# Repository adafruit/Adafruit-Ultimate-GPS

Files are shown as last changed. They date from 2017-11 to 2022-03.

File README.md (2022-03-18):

## Adafruit Ultimate GPS PCB

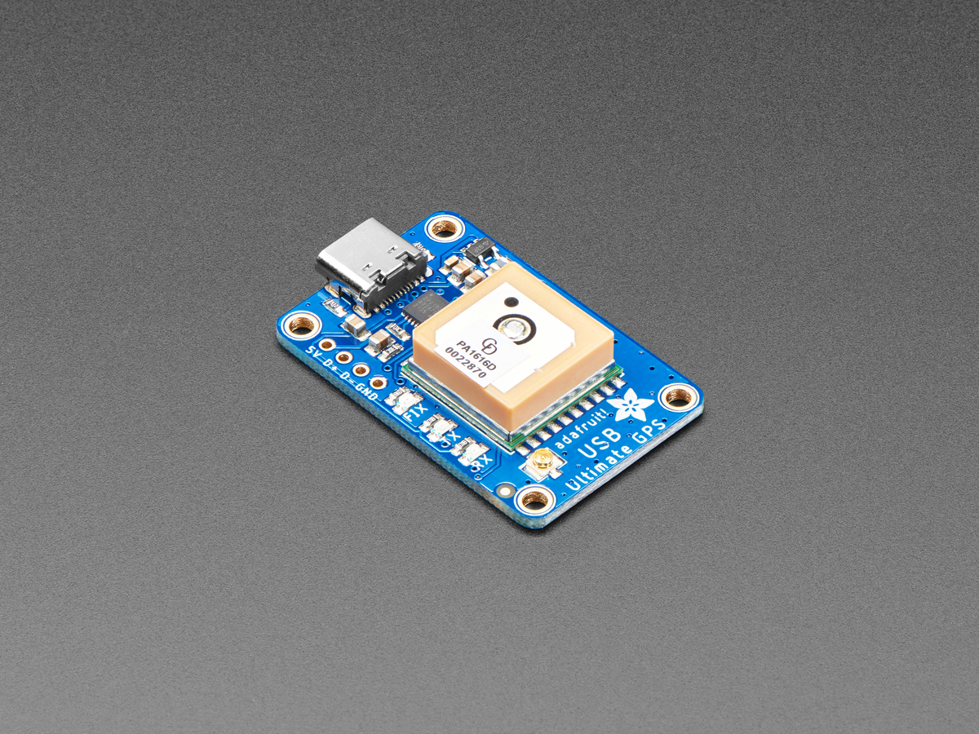
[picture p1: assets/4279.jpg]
<a href="http://www.adafruit.com/products/4279"><br/>
Click here to purchase one from the Adafruit shop</a>
Other versions:
* <a href="https://www.adafruit.com/product/746">Adafruit Ultimate GPS Breakout</a>
* <a href="https://www.adafruit.com/product/3133">Adafruit Ultimate GPS FeatherWing</a>
* <a href="https://www.adafruit.com/product/1272">Adafruit Ultimate GPS Logger Shield</a>
* <a href="https://www.adafruit.com/product/2324">Adafruit Ultimate GPS HAT for Raspberry Pi</a>
* <a href="https://www.adafruit.com/product/1059">Flora Wearable Ultimate GPS Module</a>

PCB files for the Adafruit Ultimate GPS. 

Format is EagleCAD schematic and board layout
* https://www.adafruit.com/product/4279
* https://www.adafruit.com/product/746
* https://www.adafruit.com/product/3133
* https://www.adafruit.com/product/1272
* https://www.adafruit.com/product/2324
* https://www.adafruit.com/product/1059

### Description

These boards are built around the MTK3339 chipset, a no-nonsense, high-quality GPS module that can track up to 22 satellites on 66 channels, has an excellent high-sensitivity receiver (-165 dBm tracking!), and a built-in antenna. It can do up to 10 location updates a second for high speed, high sensitivity logging, or tracking. Power usage is incredibly low, only 20 mA during navigation.

We believe this is the Ultimate GPS module, so we named it that. It's got everything you want and more:

* -165 dBm sensitivity, 10 Hz updates, 66 channels
* 5V friendly design and only 20mA current draw
* RTC battery-compatible
* Built-in datalogging
* PPS output on fix
* Internal patch antenna + u.FL connector for external active antenna
* Fix status LED
* Pulse-Per-Second output

### License

Adafruit invests time and resources providing this open source design, please support Adafruit and open-source hardware by purchasing products from [Adafruit](https://www.adafruit.com)!

Designed by Limor Fried/Ladyada for Adafruit Industries.

Creative Commons Attribution/Share-Alike, all text above must be included in any redistribution. 
See license.txt for additional details.

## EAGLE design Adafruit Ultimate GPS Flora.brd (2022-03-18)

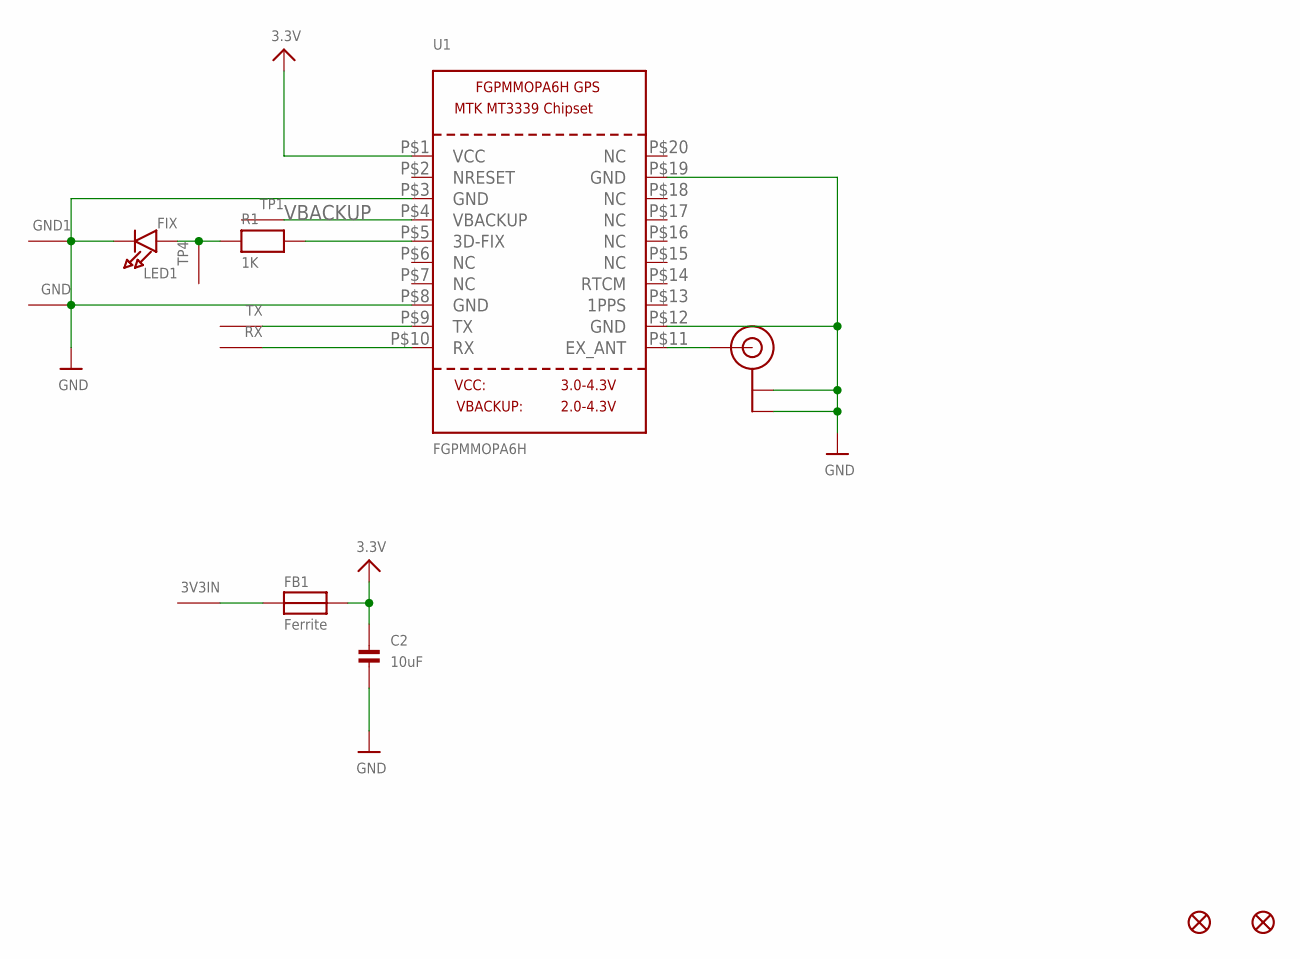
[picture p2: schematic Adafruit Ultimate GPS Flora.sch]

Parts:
3V3IN: SEWTAP-2.0IN; SEWINGTAP_2.0
C2: 10uF; 0805
FB1: Ferrite; 0805
FID1, FID2: FIDUCIAL""; FIDUCIAL_1MM
GND, GND1: SEWTAP-2.0IN; SEWINGTAP_2.0
LED1: FIX; CHIPLED_0805
R1: 1K; 0805
RX: SEWTAP-2.0IN; SEWINGTAP_2.0
TP1, TP4: SEWTAP-2.0IN; SEWINGTAP_2.0
TX: SEWTAP-2.0IN; SEWINGTAP_2.0
U1: FGPMMOPA6H
U$20: U.FL

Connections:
3.3V: C2.1, FB1.2, U1.P$1 (VCC)
GND: C2.2, GND.P$1, GND1.P$1, LED1.C, U1.P$3 (GND), U1.P$8 (GND), U1.P$12 (GND), U1.P$19 (GND), U$20.P$1 (GND), U$20.P$2 (GND)
unnamed: LED1.A, R1.1, TP4.P$1
unnamed: R1.2, U1.P$5 (3D-FIX)
unnamed: 3V3IN.P$1, FB1.1
unnamed: U1.P$11 (EX_ANT), U$20.P$3 (SIGNAL)
RX: RX.P$1, U1.P$10 (RX)
TX: TX.P$1, U1.P$9 (TX)
VBACKUP: TP1.P$1, U1.P$4 (VBACKUP)

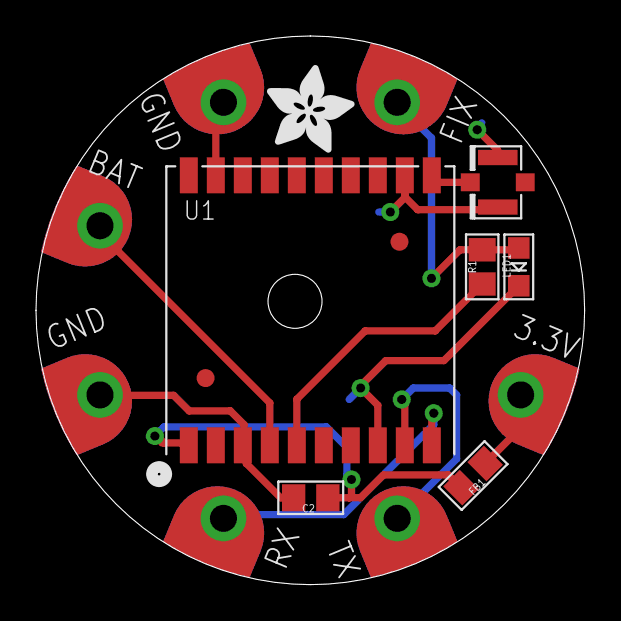
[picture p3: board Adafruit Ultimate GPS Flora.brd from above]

Board: 2 copper layers, 30.5 x 30.5 mm, 17 parts (1 on the bottom side), 9 nets.

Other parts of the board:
U$6: ADAFRUIT_5MM
U$7: FLORASMALL

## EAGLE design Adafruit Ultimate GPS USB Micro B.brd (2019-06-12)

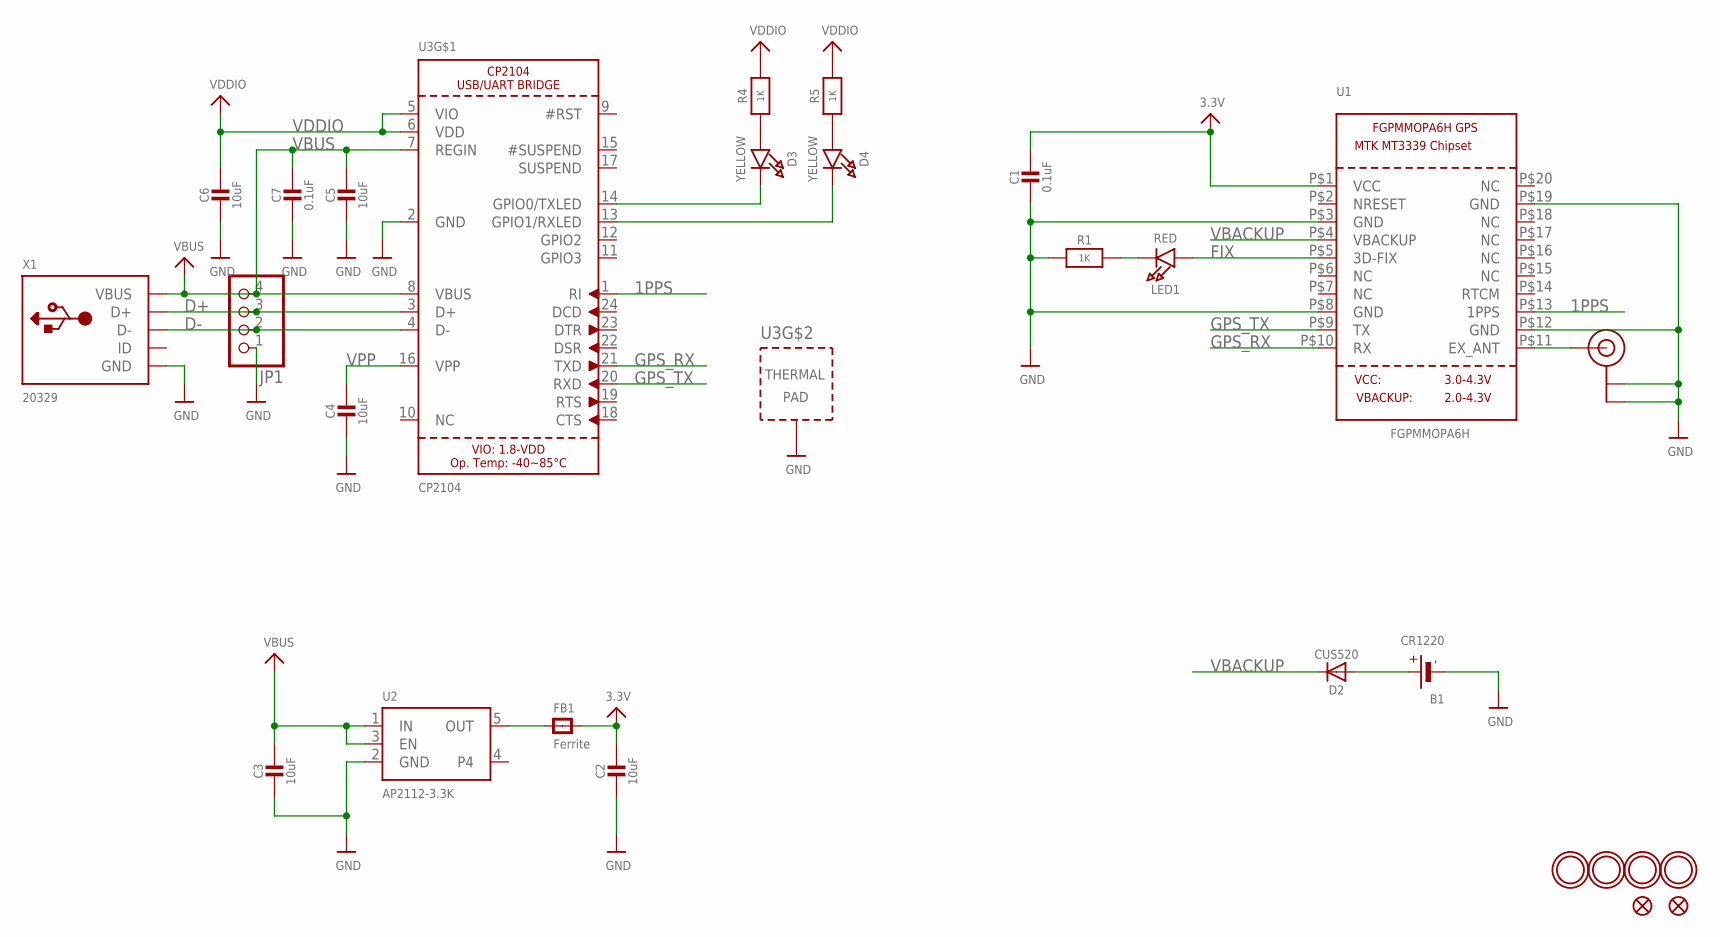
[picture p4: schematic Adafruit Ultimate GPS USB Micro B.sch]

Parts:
B1: CR1220
C1, C7: 0.1uF; 0603-NO
C2, C3, C4, C5, C6: 10uF; 0805-NO
D2: CUS520; SOD-323
D3, D4: YELLOW; CHIPLED_0805_NOOUTLINE
FB1: Ferrite; 0805-NO
FID1, FID2: FIDUCIAL_1MM
JP1: HEADER-1X4ROUND; 1X04_ROUND
LED1: RED; CHIPLED_0805_NOOUTLINE
R1, R4, R5: 1K; 0603-NO
U1: FGPMMOPA6H
U2: AP2112-3.3K; SOT23-5
U3: CP2104; QFN24_4MM_SMSC
U$8, U$9, U$35, U$36: MOUNTINGHOLE2.5; MOUNTINGHOLE_2.5_PLATED
U$20: U.FL
X1: 20329; 4UCONN_20329_V2

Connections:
1PPS: U1.P$13 (1PPS), U3.1 (RI)
3.3V: C1.1, C2.1, FB1.2, U1.P$1 (VCC)
D+: JP1.3, U3.3 (D+), X1.D+
D-: JP1.2, U3.4 (D-), X1.D-
FIX: LED1.A, U1.P$5 (3D-FIX)
GND: B1.-, C1.2, C2.2, C3.2, C4.2, C5.2, C6.2, C7.2, JP1.1, R1.1, U1.P$3 (GND), U1.P$8 (GND), U1.P$12 (GND), U1.P$19 (GND), U2.2 (GND), U3.2 (GND), U3.THERM (TP), U$20.P$1 (GND), U$20.P$2 (GND), X1.BASE@1 (GND), X1.BASE@2 (GND), X1.GND, X1.SPRT@1 (GND), X1.SPRT@2 (GND), X1.SPRT@3 (GND), X1.SPRT@4 (GND)
GPS_RX: U1.P$10 (RX), U3.21 (TXD)
GPS_TX: U1.P$9 (TX), U3.20 (RXD)
unnamed: B1.+$1 (+), B1.+$2 (+), D2.A
unnamed: LED1.C, R1.2
unnamed: FB1.1, U2.5 (OUT)
unnamed: U1.P$11 (EX_ANT), U$20.P$3 (SIGNAL)
unnamed: D3.A, R4.1
unnamed: D4.A, R5.1
unnamed: D3.C, U3.14 (GPIO0/TXLED)
unnamed: D4.C, U3.13 (GPIO1/RXLED)
VBACKUP: D2.C, U1.P$4 (VBACKUP)
VBUS: C3.1, C5.1, C7.1, JP1.4, U2.1 (IN), U2.3 (EN), U3.7 (REGIN), U3.8 (VBUS), X1.VBUS
VDDIO: C6.1, R4.2, R5.2, U3.5 (VIO), U3.6 (VDD)
VPP: C4.1, U3.16 (VPP)

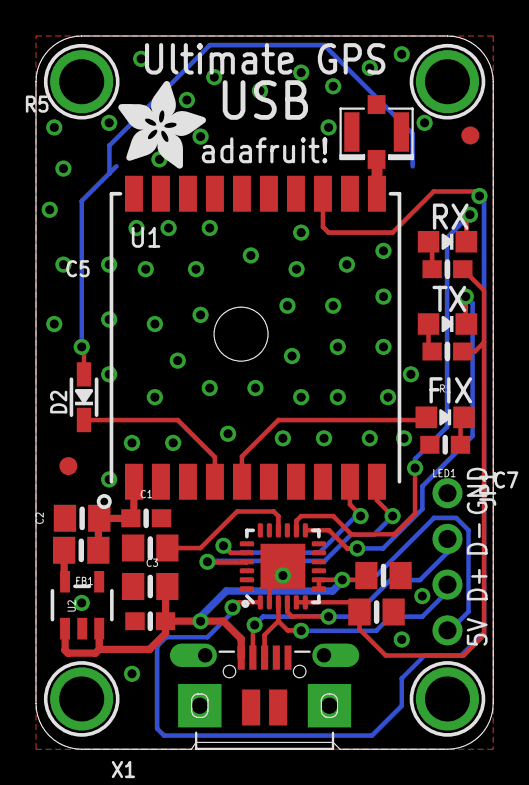
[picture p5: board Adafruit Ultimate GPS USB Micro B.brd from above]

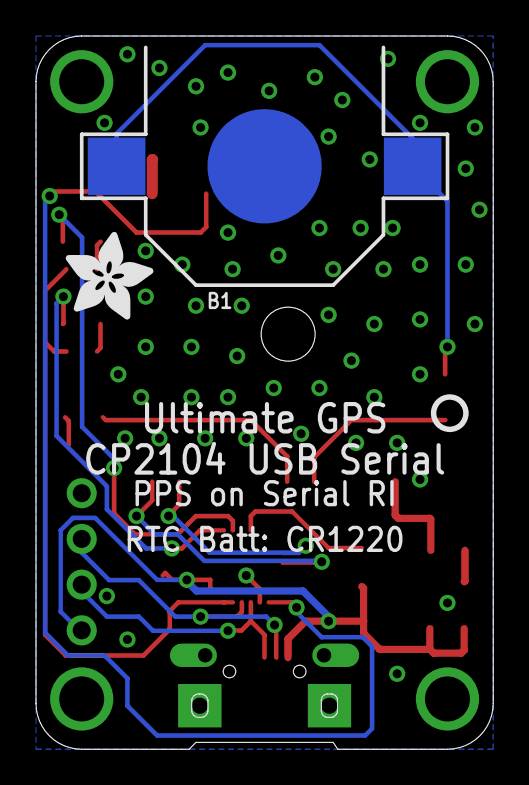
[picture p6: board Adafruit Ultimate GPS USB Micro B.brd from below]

Board: 2 copper layers, 25.4 x 39.6 mm, 31 parts (3 on the bottom side), 20 nets.

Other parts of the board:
U$13, U$18: ADAFRUIT_5MM
U$16: PCBFEAT-REV-040

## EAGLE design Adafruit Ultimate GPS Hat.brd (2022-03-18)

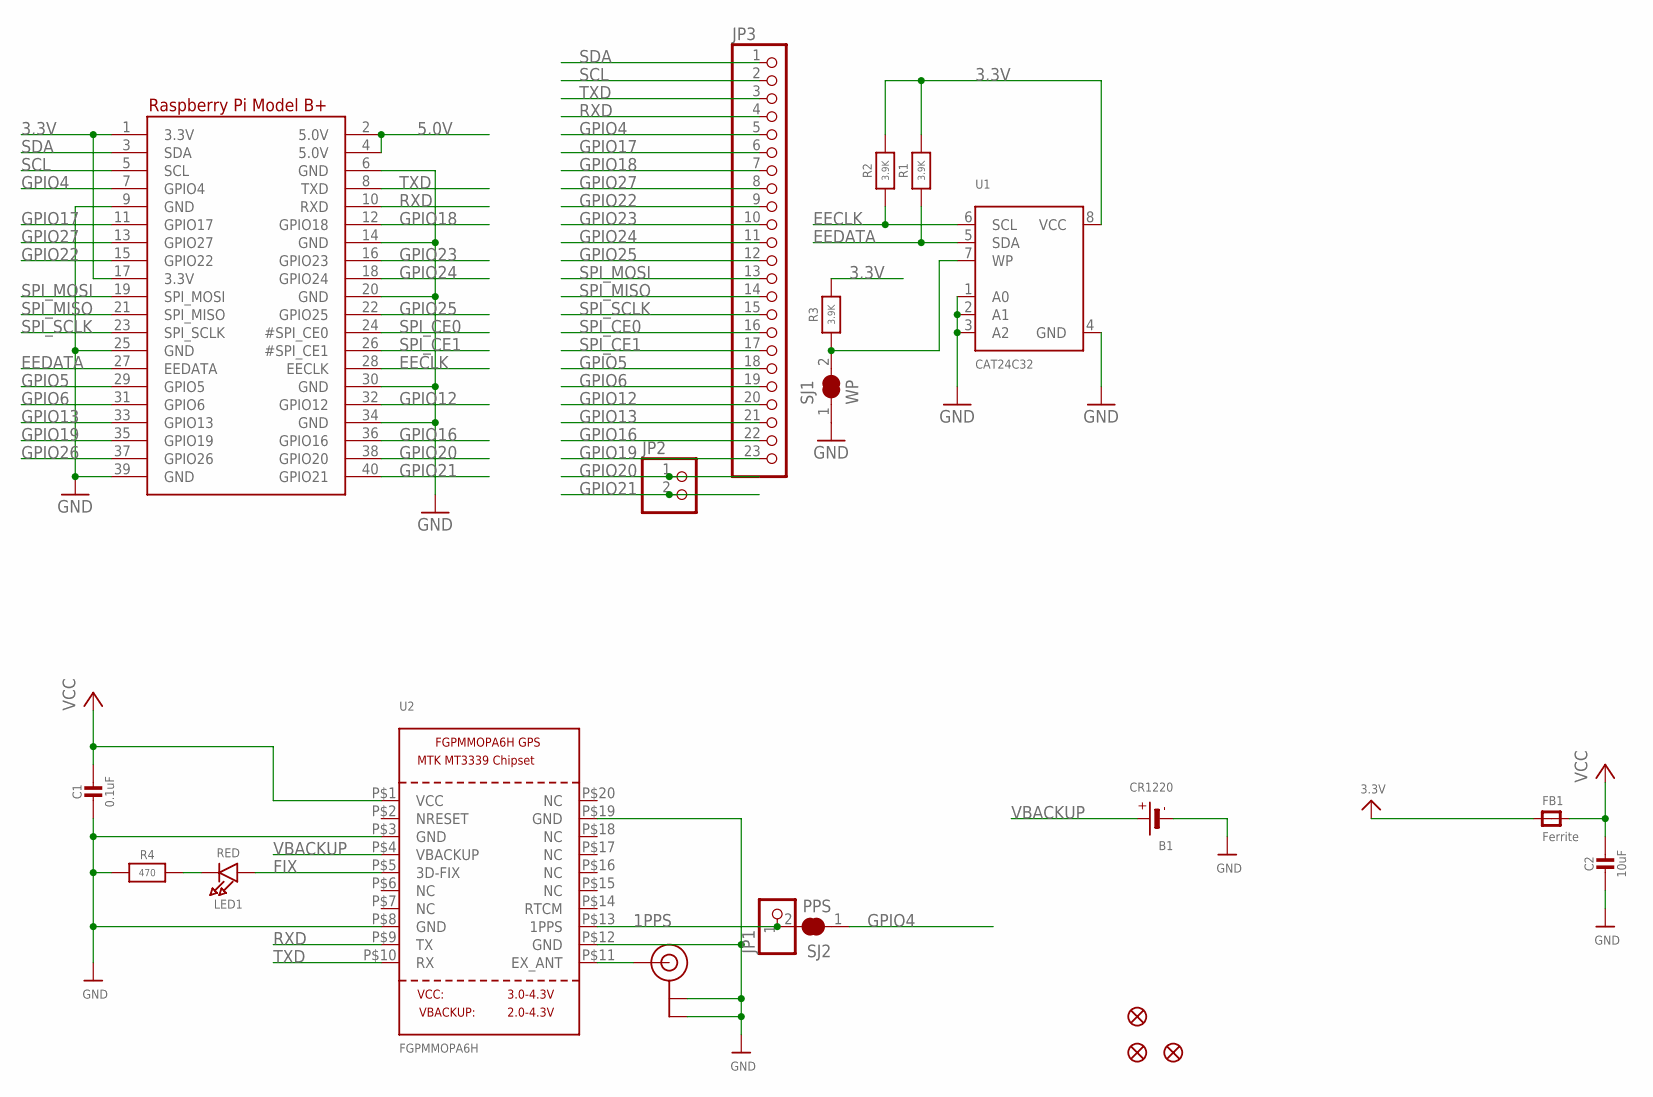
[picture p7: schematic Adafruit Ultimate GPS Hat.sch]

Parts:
B1: CR1220
C1: 0.1uF; 0805-NO
C2: 10uF; 0805-NO
FB1: Ferrite; 0805
FID1, FID2, FID3: FIDUCIAL_1MM
JP1: PINHD-1X1CB; 1X01-CLEANBIG
JP2: HEADER-1X2ROUND; 1X02_ROUND
JP3: HEADER-1X23; 1X23_ROUND_70MIL
LED1: RED; CHIPLED_0805
R1, R2, R3: 3.9K; 0805-NO
R4: 470; 0805-NO
RPI1: RASPBERRYPI_BPLUS_HATSLOTS; PI_HAT_SLOTS
SJ1: WP; SOLDERJUMPER_CLOSEDWIRE
SJ2: PPS; SOLDERJUMPER_CLOSEDWIRE
U1: CAT24C32; SOIC8_150MIL
U2: FGPMMOPA6H
U$20: U.FL

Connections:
1PPS: JP1.1, SJ2.2, U2.P$13 (1PPS)
3.3V: FB1.1, R1.2, R2.2, R3.2, RPI1.1 (3.3V), RPI1.17 (3.3V), U1.8 (VCC)
5.0V: RPI1.2 (5.0V), RPI1.4 (5.0V)
EECLK: R2.1, RPI1.28 (EECLK), U1.6 (SCL)
EEDATA: R1.1, RPI1.27 (EEDATA), U1.5 (SDA)
FIX: LED1.A, U2.P$5 (3D-FIX)
GND: B1.-, C1.2, C2.2, R4.1, RPI1.6 (GND), RPI1.9 (GND), RPI1.14 (GND), RPI1.20 (GND), RPI1.25 (GND), RPI1.30 (GND), RPI1.34 (GND), RPI1.39 (GND), SJ1.1, U1.1 (A0), U1.2 (A1), U1.3 (A2), U1.4 (GND), U2.P$3 (GND), U2.P$8 (GND), U2.P$12 (GND), U2.P$19 (GND), U$20.P$1 (GND), U$20.P$2 (GND)
GPIO4: JP3.5, RPI1.7 (GPIO4), SJ2.1
GPIO5: JP3.18, RPI1.29 (GPIO5)
GPIO6: JP3.19, RPI1.31 (GPIO6)
GPIO12: JP3.20, RPI1.32 (GPIO12)
GPIO13: JP3.21, RPI1.33 (GPIO13)
GPIO16: JP3.22, RPI1.36 (GPIO16)
GPIO17: JP3.6, RPI1.11 (GPIO17)
GPIO18: JP3.7, RPI1.12 (GPIO18)
GPIO19: JP3.23, RPI1.35 (GPIO19)
GPIO20: JP2.1, RPI1.38 (GPIO20)
GPIO21: JP2.2, RPI1.40 (GPIO21)
GPIO22: JP3.9, RPI1.15 (GPIO22)
GPIO23: JP3.10, RPI1.16 (GPIO23)
GPIO24: JP3.11, RPI1.18 (GPIO24)
GPIO25: JP3.12, RPI1.22 (GPIO25)
GPIO26: RPI1.37 (GPIO26)
GPIO27: JP3.8, RPI1.13 (GPIO27)
unnamed: R3.1, SJ1.2, U1.7 (WP)
unnamed: LED1.C, R4.2
unnamed: U2.P$11 (EX_ANT), U$20.P$3 (SIGNAL)
RXD: JP3.4, RPI1.10 (RXD), U2.P$9 (TX)
SCL: JP3.2, RPI1.5 (SCL)
SDA: JP3.1, RPI1.3 (SDA)
SPI_CE0: JP3.16, RPI1.24 (#SPI_CE0)
SPI_CE1: JP3.17, RPI1.26 (#SPI_CE1)
SPI_MISO: JP3.14, RPI1.21 (SPI_MISO)
SPI_MOSI: JP3.13, RPI1.19 (SPI_MOSI)
SPI_SCLK: JP3.15, RPI1.23 (SPI_SCLK)
TXD: JP3.3, RPI1.8 (TXD), U2.P$10 (RX)
VBACKUP: B1.+$1 (+), B1.+$2 (+), U2.P$4 (VBACKUP)
VCC: C1.1, C2.1, FB1.2, U2.P$1 (VCC)

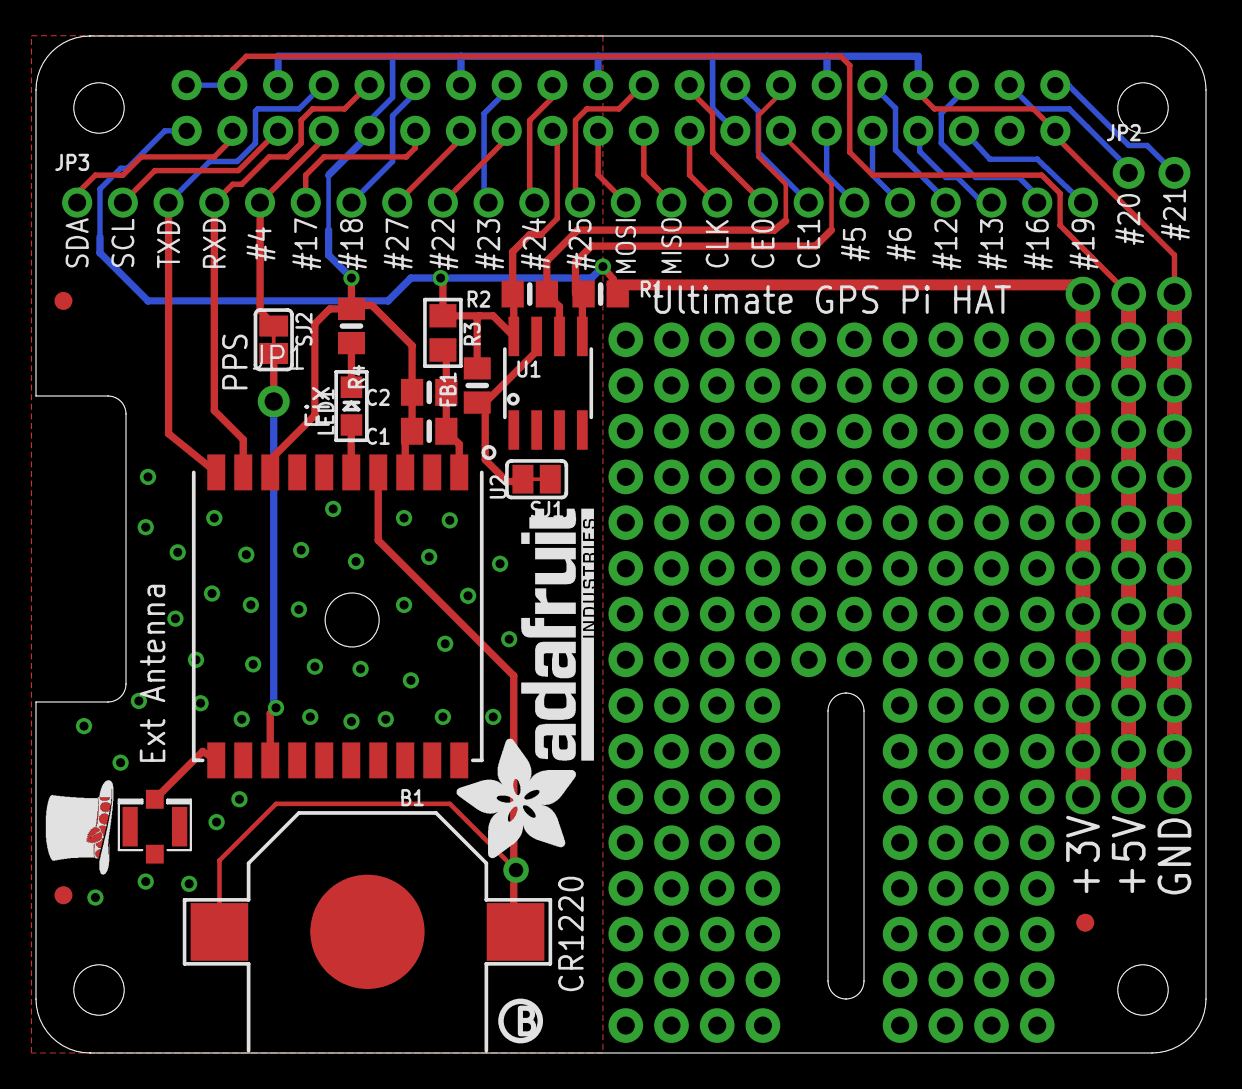
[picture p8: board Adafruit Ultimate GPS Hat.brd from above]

Board: 2 copper layers, 65.0 x 56.5 mm, 24 parts (0 on the bottom side), 37 nets.

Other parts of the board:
U$3: ADAFRUIT_TEXT_20MM
U$4: PIHATLOGO
U$6: PCBFEAT-REV-056

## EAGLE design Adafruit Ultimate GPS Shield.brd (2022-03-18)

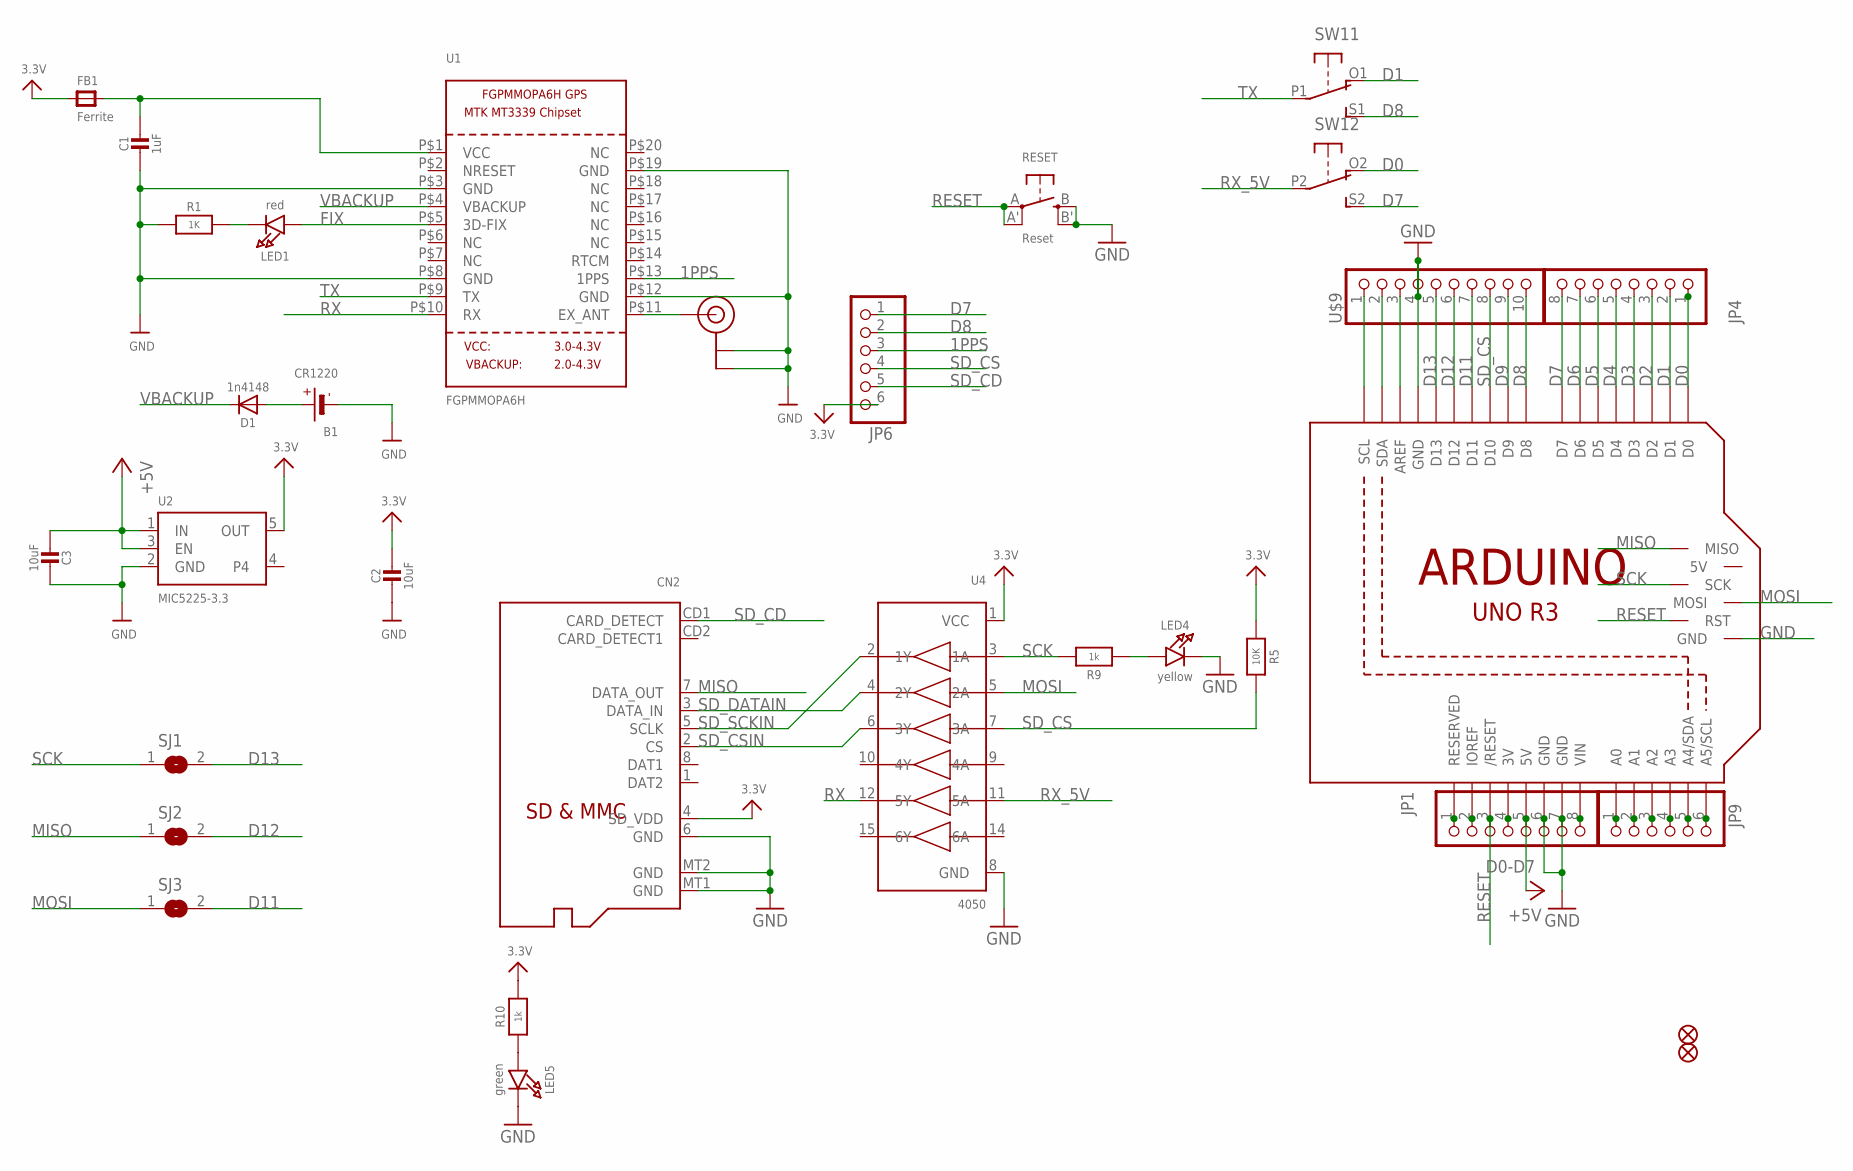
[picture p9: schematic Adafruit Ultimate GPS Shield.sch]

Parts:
B1: CR1220
C1: 1uF; 0805-NO
C2, C3: 10uF; 0805-NO
CN2: MICROSD
D1: 1n4148; SOD-323
FB1: Ferrite; 0805
FID1, FID2: FIDUCIAL""; FIDUCIAL_1MM
JP1: D0-D7; 1X08-BIG
JP4: PINHD-1X8BIG; 1X08-BIG
JP6, JP9: PINHD-1X6B; 1X06-BIG
LED1: red; CHIPLED_0805_NOOUTLINE
LED4: yellow; CHIPLED_0805_NOOUTLINE
LED5: green; CHIPLED_0805_NOOUTLINE
M1: ARDUINO_R3_ICSP_NODIM; ARDUINOR3_ICSP_NODIM
R1: 1K; 0805-NO
R5: 10K; 0805-NO
R9, R10: 1k; 0805-NO
RESET: Reset; EVQ-Q2
SJ1, SJ2, SJ3: SOLDERJUMPER; SOLDERJUMPER_ARROW_NOPASTE
SW1: DPDT-EG1390; EG1390
U1: FGPMMOPA6H
U2: MIC5225-3.3; SOT23-5
U4: 4050; SOIC16
U$9: PINHD-1X10; 1X10-BIG
U$20: U.FL

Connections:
1PPS: JP6.3, U1.P$13 (1PPS)
3.3V: C2.1, CN2.4 (SD_VDD), FB1.1, JP6.6, R5.1, R10.2, U2.5 (OUT), U4.1 (VCC)
3V: JP1.4, M1.3V
+5V: C3.1, JP1.5, M1.5V, U2.1 (IN), U2.3 (EN)
A0: JP9.1, M1.A0
A1: JP9.2, M1.A1
A2: JP9.3, M1.A2
A3: JP9.4, M1.A3
A4: JP9.5, M1.A4 (A4/SDA)
A5: JP9.6, M1.A5 (A5/SCL)
AREF: M1.AREF, U$9.3
D0: JP4.1, M1.D0, SW1.O2 (O)
D1: JP4.2, M1.D1, SW1.O1 (O)
D2: JP4.3, M1.D2
D3: JP4.4, M1.D3
D4: JP4.5, M1.D4
D5: JP4.6, M1.D5
D6: JP4.7, M1.D6
D7: JP4.8, JP6.1, M1.D7, SW1.S2 (S)
D8: JP6.2, M1.D8, SW1.S1 (S), U$9.10
D9: M1.D9, U$9.9
D11: M1.D11, SJ3.2, U$9.7
D12: M1.D12, SJ2.2, U$9.6
D13: M1.D13, SJ1.2, U$9.5
FIX: LED1.A, U1.P$5 (3D-FIX)
GND: B1.-, C1.2, C2.2, C3.2, CN2.6 (GND), CN2.MT1 (GND), CN2.MT2 (GND), JP1.6, JP1.7, LED4.C, LED5.C, M1.GND, M1.GND@1 (GND), M1.GND@2 (GND), M1.GND@3 (GND), R1.1, RESET.B (S), RESET.B' (S1), U1.P$3 (GND), U1.P$8 (GND), U1.P$12 (GND), U1.P$19 (GND), U2.2 (GND), U4.8 (GND), U$9.4, U$20.P$1 (GND), U$20.P$2 (GND)
IOREF: JP1.2, M1.IOREF
MISO: CN2.7 (DATA_OUT), M1.MISO, SJ2.1
MOSI: M1.MOSI, SJ3.1, U4.5 (2A)
unnamed: C1.1, FB1.2, U1.P$1 (VCC)
unnamed: LED1.C, R1.2
unnamed: B1.+$1 (+), B1.+$2 (+), D1.A
unnamed: U1.P$11 (EX_ANT), U$20.P$3 (SIGNAL)
unnamed: LED4.A, R9.1
unnamed: LED5.A, R10.1
NC: JP1.1, M1.RESERVED
RESET: JP1.3, M1.RESET (/RESET), M1.RESET_ICSP (RST), RESET.A, RESET.A' (P1)
RX: U1.P$10 (RX), U4.12 (5Y)
RX_5V: SW1.P2, U4.11 (5A)
SCK: M1.SCK, R9.2, SJ1.1, U4.3 (1A)
SCL: M1.SCL, U$9.1
SDA: M1.SDA, U$9.2
SD_CD: CN2.CD1 (CARD_DETECT), JP6.5
SD_CS: JP6.4, M1.D10, R5.2, U4.7 (3A), U$9.8
SD_CSIN: CN2.2 (CS), U4.6 (3Y)
SD_DATAIN: CN2.3 (DATA_IN), U4.4 (2Y)
SD_SCKIN: CN2.5 (SCLK), U4.2 (1Y)
TX: SW1.P1, U1.P$9 (TX)
VBACKUP: D1.C, U1.P$4 (VBACKUP)
VIN: JP1.8, M1.VIN

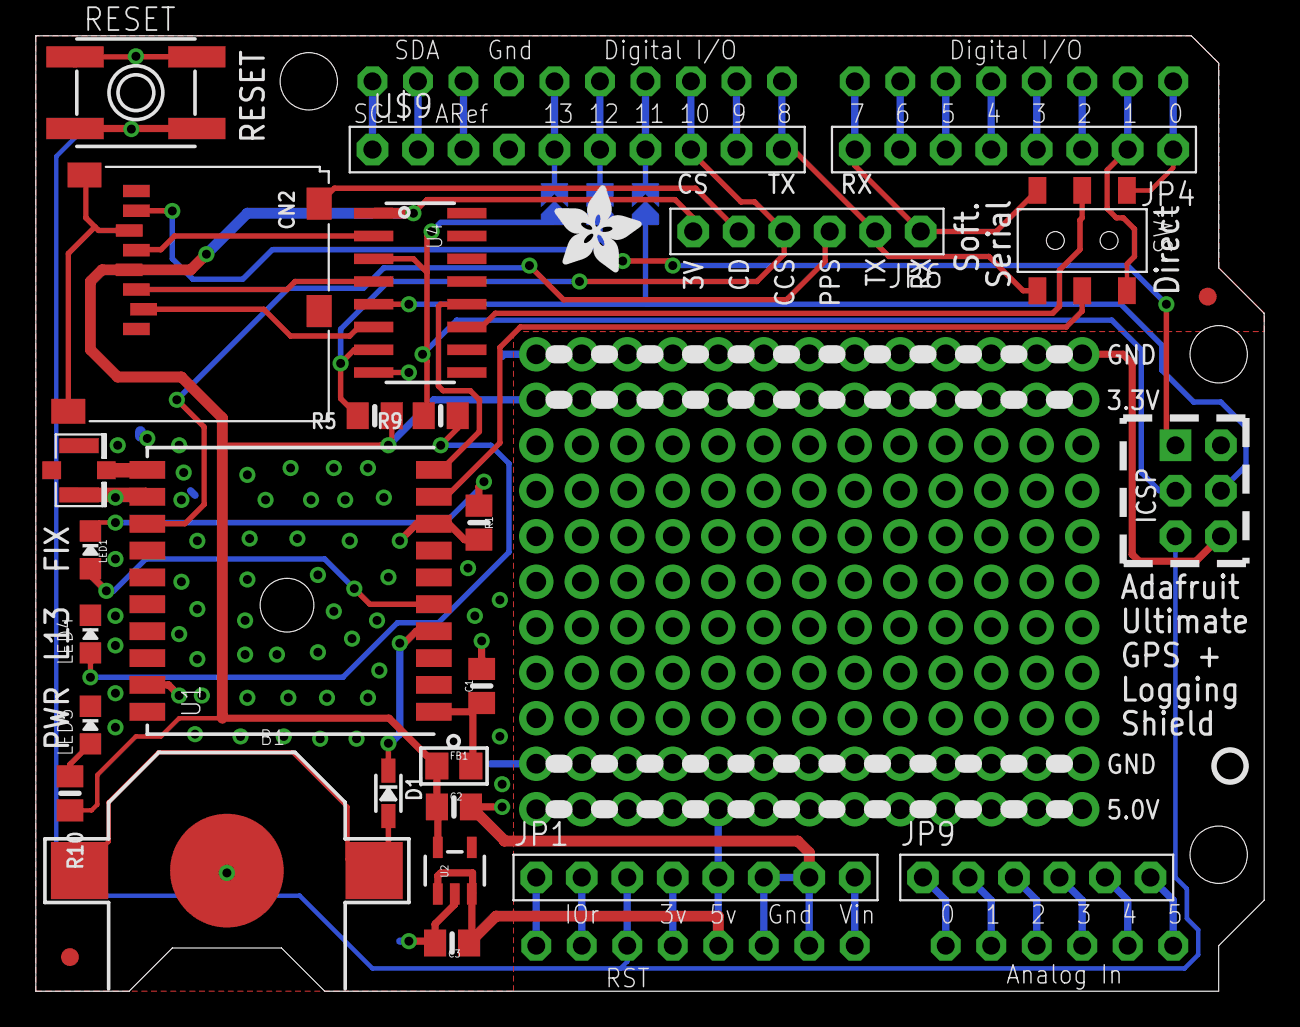
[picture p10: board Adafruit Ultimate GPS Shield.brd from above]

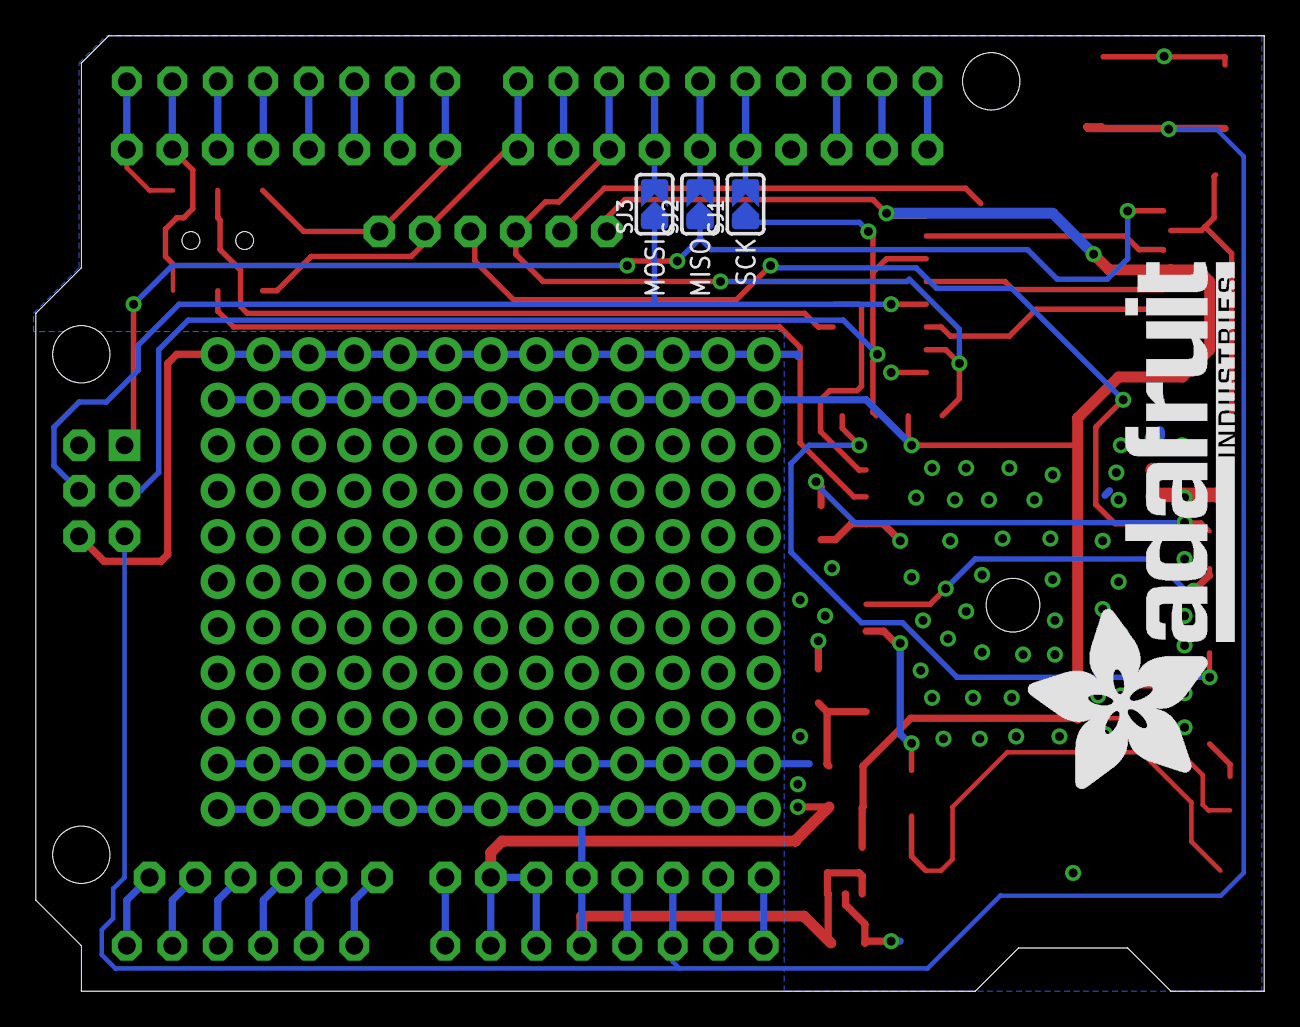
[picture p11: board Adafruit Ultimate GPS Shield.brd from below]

Board: 2 copper layers, 68.6 x 53.3 mm, 34 parts (4 on the bottom side), 50 nets.

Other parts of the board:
U$13: ADAFRUIT_5MM
U$15: ADAFRUIT_TEXT_30MM
U$16: PCBFEAT-REV-040

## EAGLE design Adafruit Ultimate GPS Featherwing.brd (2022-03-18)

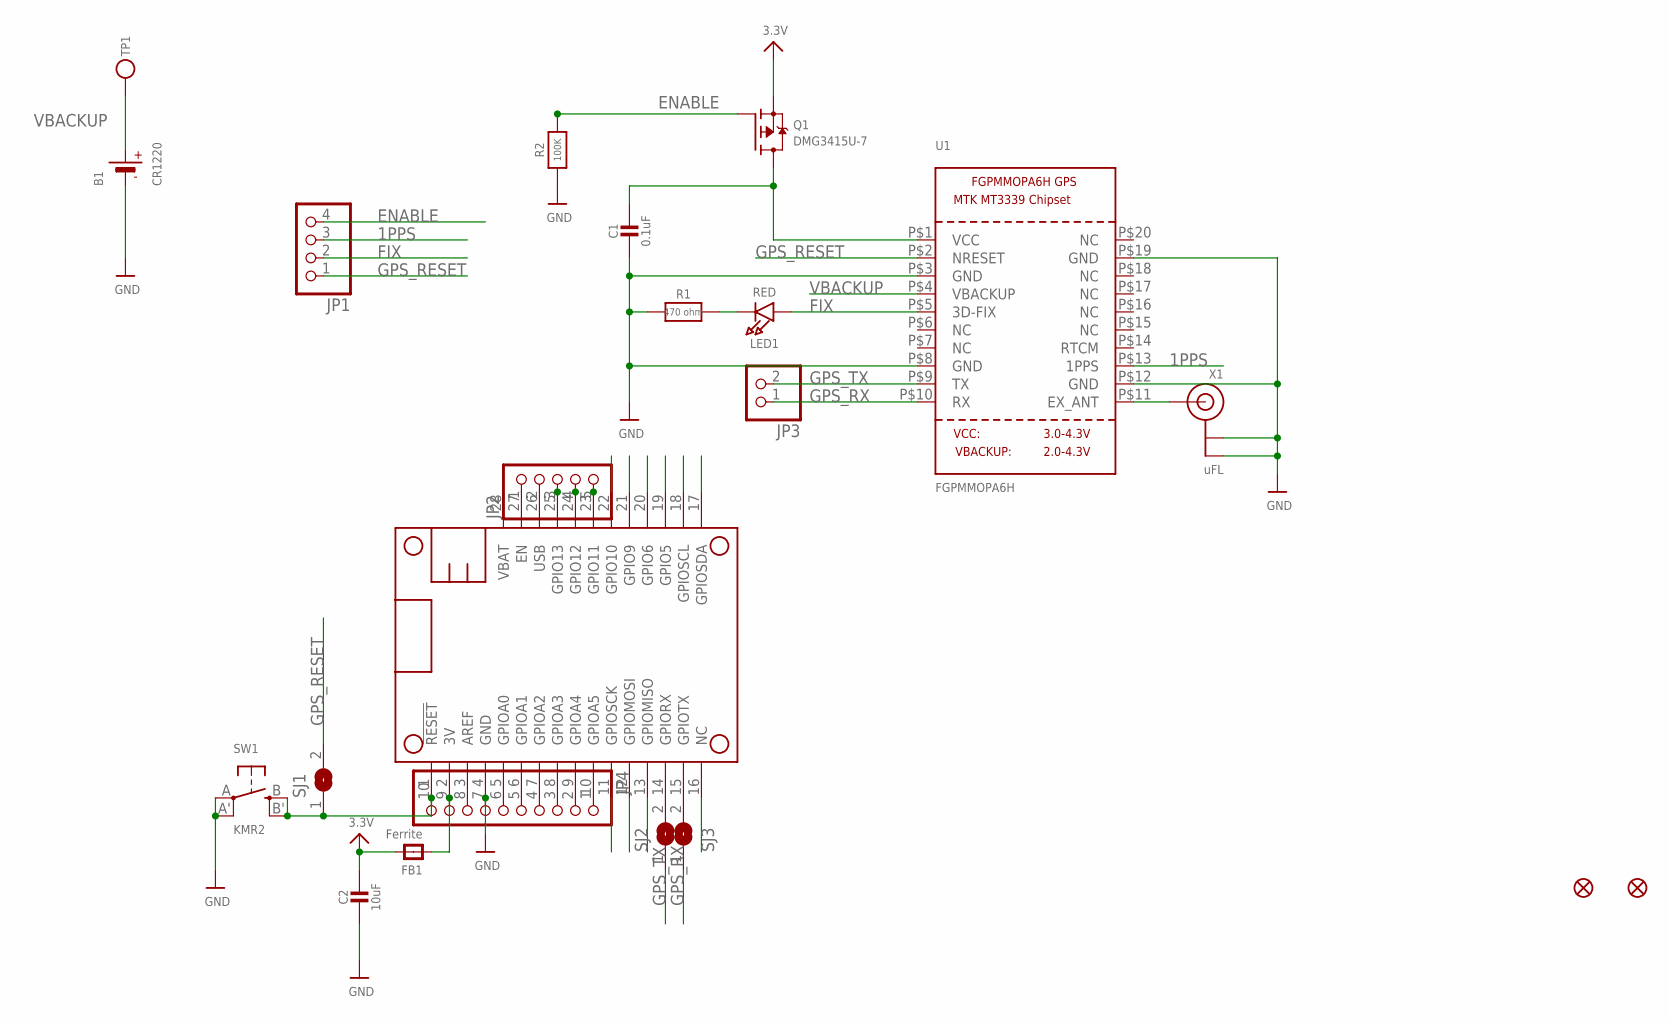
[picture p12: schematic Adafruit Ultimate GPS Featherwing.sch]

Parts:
B1: CR1220; CR1220-2
C1: 0.1uF; 0805-NO
C2: 10uF; 0805-NO
FB1: Ferrite; 0805-NO
FID1, FID2: FIDUCIAL""; FIDUCIAL_1MM
JP1: HEADER-1X4ROUND; 1X04_ROUND
JP2: HEADER-1X570MIL; 1X05_ROUND_70
JP3: HEADER-1X2ROUND; 1X02_ROUND
JP4: HEADER-1X10ROUND; 1X10_ROUND
LED1: RED; CHIPLED_0805_NOOUTLINE
MS1: FEATHERWING
Q1: DMG3415U-7; SOT23-WIDE
R1: 470 ohm; 0805-NO
R2: 100K; 0805-NO
SJ1: SOLDERJUMPER; SOLDERJUMPER_ARROW_NOPASTE
SJ2, SJ3: SOLDERJUMPERCLOSED; SOLDERJUMPER_CLOSEDWIRE
SW1: KMR2; BTN_KMR2_4.6X2.8
TP1: TESTPOINTROUND1.5MM; TESTPOINT_ROUND_1.5MM
U1: FGPMMOPA6H
X1: uFL; U.FL

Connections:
1PPS: JP1.3, U1.P$13 (1PPS)
3.3V: C2.1, FB1.2, Q1.2 (S)
3V: FB1.1, JP4.9, MS1.2 (3V)
A: JP4.6, MS1.5 (GPIOA0)
AREF: JP4.8, MS1.3 (AREF)
B: JP4.5, MS1.6 (GPIOA1)
C: JP4.4, MS1.7 (GPIOA2)
D: JP4.3, MS1.8 (GPIOA3)
E: JP4.2, MS1.9 (GPIOA4)
EN: JP2.1, MS1.27 (EN)
ENABLE: JP1.4, Q1.1 (G), R2.2
F: JP4.1, MS1.10 (GPIOA5)
FIX: JP1.2, LED1.A, U1.P$5 (3D-FIX)
G: MS1.16 (NC)
GND: B1.-, C1.2, C2.2, JP4.7, MS1.4 (GND), R1.1, R2.1, SW1.A, SW1.A' (P1), U1.P$3 (GND), U1.P$8 (GND), U1.P$12 (GND), U1.P$19 (GND), X1.1 (GND), X1.2 (GND)
GPS_RESET: JP1.1, SJ1.2, U1.P$2 (NRESET)
GPS_RX: JP3.1, SJ3.1, U1.P$10 (RX)
GPS_TX: JP3.2, SJ2.1, U1.P$9 (TX)
H: MS1.19 (GPIO5)
I: MS1.20 (GPIO6)
J: MS1.21 (GPIO9)
K: MS1.22 (GPIO10)
L: JP2.5, MS1.23 (GPIO11)
M: JP2.4, MS1.24 (GPIO12)
MISO: MS1.13 (GPIOMISO)
MOSI: MS1.12 (GPIOMOSI)
N: JP2.3, MS1.25 (GPIO13)
unnamed: LED1.C, R1.2
unnamed: U1.P$11 (EX_ANT), X1.3 (SIGNAL)
unnamed: C1.1, Q1.3 (D), U1.P$1 (VCC)
RST: JP4.10, MS1.1 (!RESET), SJ1.1, SW1.B (S), SW1.B' (S1)
RX: MS1.14 (GPIORX), SJ2.2
SCK: MS1.11 (GPIOSCK)
SCL: MS1.18 (GPIOSCL)
SDA: MS1.17 (GPIOSDA)
TX: MS1.15 (GPIOTX), SJ3.2
USB: JP2.2, MS1.26 (USB)
VBACKUP: B1.+, TP1.P$1, U1.P$4 (VBACKUP)

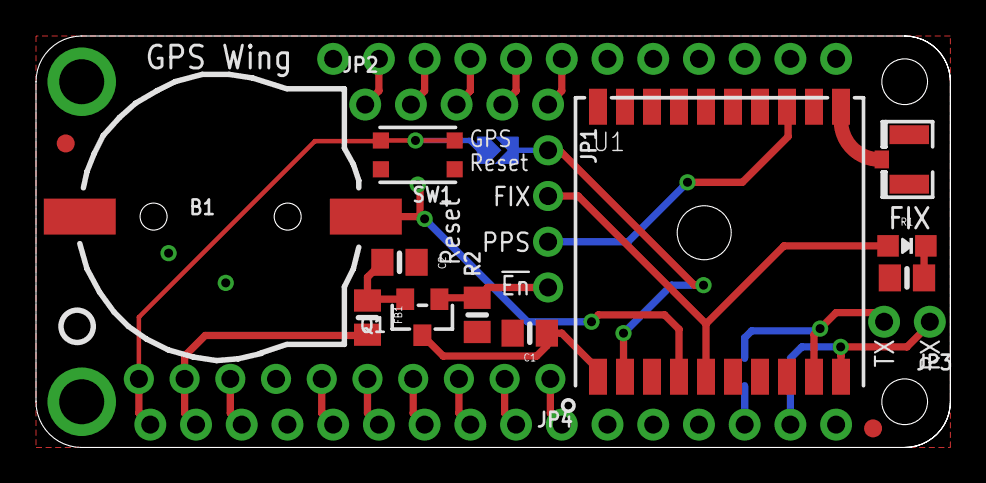
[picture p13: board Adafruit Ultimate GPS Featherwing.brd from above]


Board: 2 copper layers, 50.8 x 22.9 mm, 25 parts (6 on the bottom side), 28 nets.

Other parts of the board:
U$9: PCBFEAT-REV-040
U$10: FEATHERLOGO
U$11: ADAFRUIT_TEXT_20MM

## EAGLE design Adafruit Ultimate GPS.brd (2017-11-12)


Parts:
B1: CR1220
C1: 0.1uF; 0805-NO
C2, C3: 10uF; 0805-NO
D1: 1N4148; SOD-323
D2: CUS520; SOD-323
FB1: Ferrite; 0805-NO
FID1, FID2: FIDUCIAL""; FIDUCIAL_1MM
JP1: HEADER-1X970MIL; 1X09_ROUND_70
LED1: RED; CHIPLED_0805
R1: 1K; 0805-NO
R2, R3: 10K; 0805-NO
U1: FGPMMOPA6H
U2: MIC5225-3.3; SOT23-5
U$8, U$9: MOUNTINGHOLE2.5; MOUNTINGHOLE_2.5_PLATED
U$20: U.FL

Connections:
1PPS: JP1.1, U1.P$13 (1PPS)
3.3V: C1.1, C2.1, FB1.2, JP1.9, R3.1, U1.P$1 (VCC)
ENABLE: JP1.8, R2.1, U2.3 (EN)
FIX: JP1.6, LED1.A, U1.P$5 (3D-FIX)
GND: B1.-, C1.2, C2.2, C3.2, JP1.3, R1.1, U1.P$3 (GND), U1.P$8 (GND), U1.P$12 (GND), U1.P$19 (GND), U2.2 (GND), U$20.P$1 (GND), U$20.P$2 (GND)
unnamed: B1.+$1 (+), B1.+$2 (+), D2.A
unnamed: LED1.C, R1.2
unnamed: FB1.1, U2.5 (OUT)
unnamed: U1.P$11 (EX_ANT), U$20.P$3 (SIGNAL)
RX: D1.C, JP1.4
RX_3V: D1.A, R3.2, U1.P$10 (RX)
TX: JP1.5, U1.P$9 (TX)
VBACKUP: D2.C, JP1.7, U1.P$4 (VBACKUP)
VIN: C3.1, JP1.2, R2.2, U2.1 (IN)

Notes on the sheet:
D1+R3 restrict RX input to 3.3V

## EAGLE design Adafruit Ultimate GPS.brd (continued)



Board: 2 copper layers, 25.4 x 34.3 mm, 22 parts (3 on the bottom side), 14 nets.

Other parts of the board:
U$15: ADAFRUIT_2.5MM
U$16: PCBFEAT-REV-040
U$18: ADAFRUIT_5MM

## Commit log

2019-06-12 Add Ultimate GPS USB board files
    [Adafruit Ultimate GPS USB.brd, Adafruit Ultimate GPS USB.sch]
2022-03-17 Add USB-C board files.
    [Adafruit Ultimate GPS USB-C.brd, Adafruit Ultimate GPS USB-C.sch]
2022-03-18 Cookiecutted and added all the ultimate GPSs
    [Adafruit Ultimate GPS Featherwing.brd, Adafruit Ultimate GPS Featherwing.sch, Adafruit Ultimate GPS Flora.brd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]

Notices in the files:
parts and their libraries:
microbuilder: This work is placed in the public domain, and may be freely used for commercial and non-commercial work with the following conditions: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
